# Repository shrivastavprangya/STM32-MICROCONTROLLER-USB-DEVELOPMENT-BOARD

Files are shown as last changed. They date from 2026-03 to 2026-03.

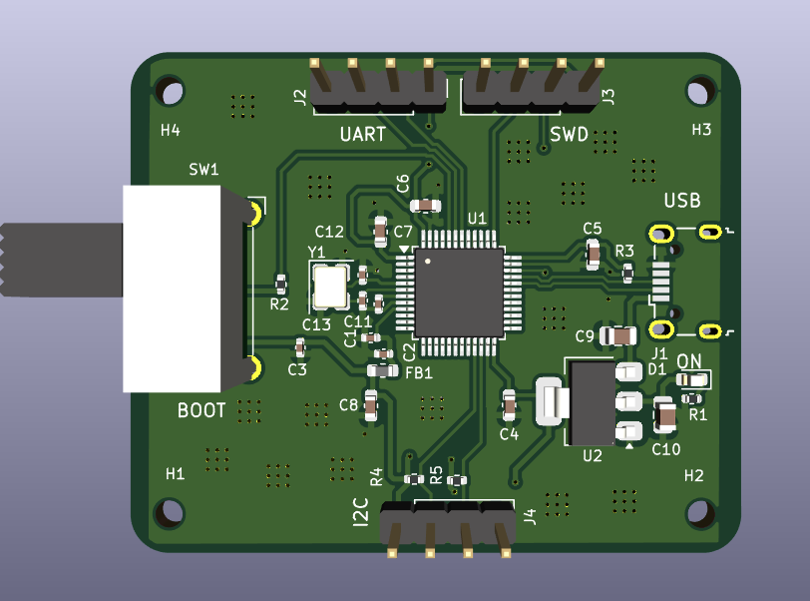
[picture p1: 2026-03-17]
STM32 TOP LAYER 3D VIEW.png

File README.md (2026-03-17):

# STM32 Microcontroller USB Development Board

This project is a custom STM32 microcontroller based USB development board designed using KiCad.  
The board includes LDO based 3.3V power regulation, USB interface for communication and power, 
external crystal oscillator for stable clock operation and GPIO expansion headers.

The PCB is designed as a 2-layer board with a dedicated ground plane for improved signal integrity 
and stable power distribution.

---

## Features

- STM32 microcontroller based development board
- USB interface for programming and communication
- 3.3V LDO voltage regulator
- External crystal oscillator for accurate clock
- Decoupling capacitors for power stability
- GPIO expansion headers
- 2-layer PCB with ground plane

---

## Design Workflow

Schematic Design  
↓  
Component Selection  
↓  
PCB Layout and Routing  
↓  
Design Rule Check (DRC)  
↓  
Gerber File Generation  
↓  
PCB Manufacturing

---

## PCB Preview

### Schematic
STM 32 PCB SCH

### PCB Layout
STM32 PCB LAYOUT

### 3D View (Top)
STM32 TOP LAYER 3D VIEW

### 3D View (Bottom)
STM32 BOTTOM LAYER 3D VIEW

---

## Project Files

- **Schematic** – KiCad schematic design files  
- **PCB Layout** – Complete PCB layout and routing files  
- **Gerber Files** – Manufacturing files used for PCB fabrication 

---

## Tools Used

- KiCad

---
## Project Structure

STM32-MICROCONTROLLER-USB-DEVELOPMENT-BOARD

│
├── Schematic
│   └── stm32_usb_board.kicad_sch
│
├── PCB
│   └── stm32_usb_board.kicad_pcb
│
├── Gerber
│   └── gerber_files.zip
│
├── Images
│   ├── pcb_top.png
│   ├── pcb_bottom.png
│   └── pcb_3d.png
│
└── README.md

## Author

**Pragya Shrivastav**  
Electronics & Communication Engineer  
PCB Design | Embedded Hardware

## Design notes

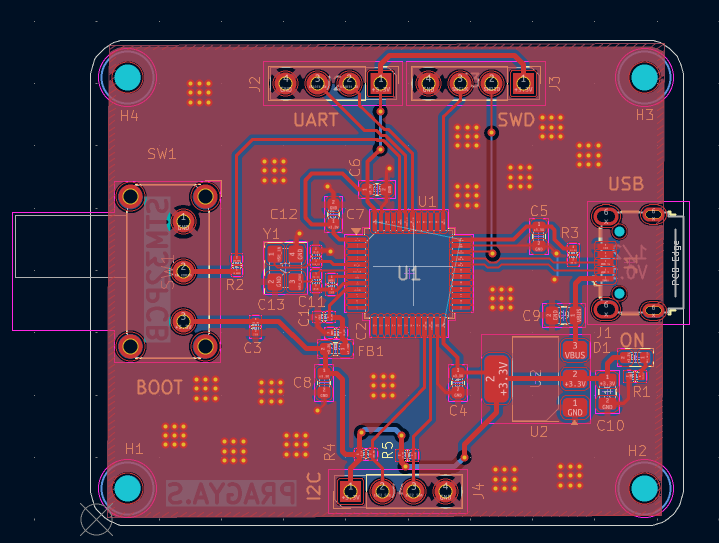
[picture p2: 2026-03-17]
STM32 PCB LAYOUT.png

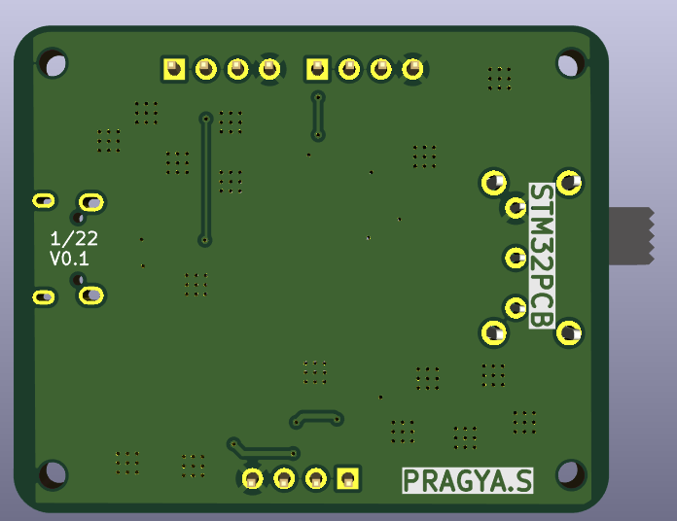
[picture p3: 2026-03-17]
STM32 BOTTOM LAYER 3D VIEW.png

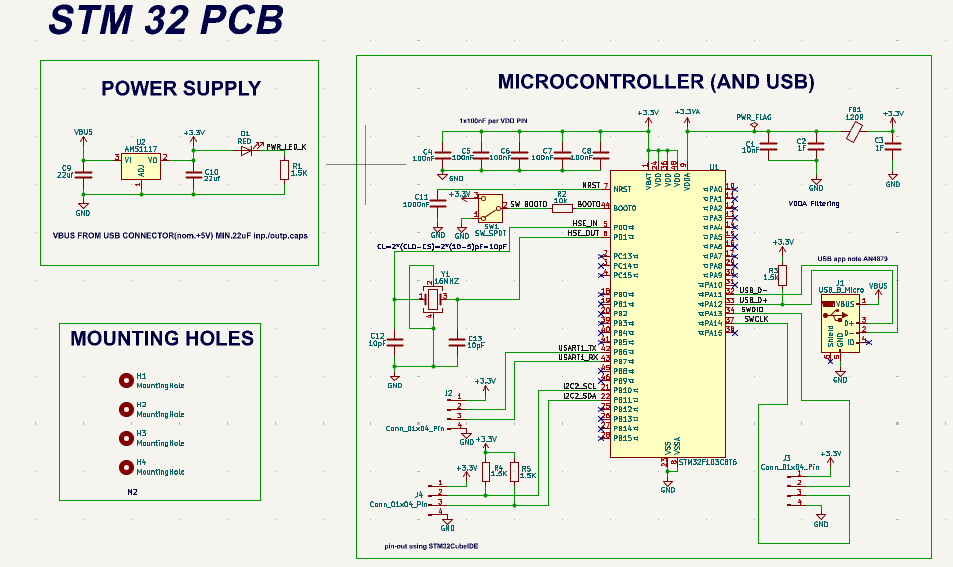
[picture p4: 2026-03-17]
STM 32 PCB SCH.png

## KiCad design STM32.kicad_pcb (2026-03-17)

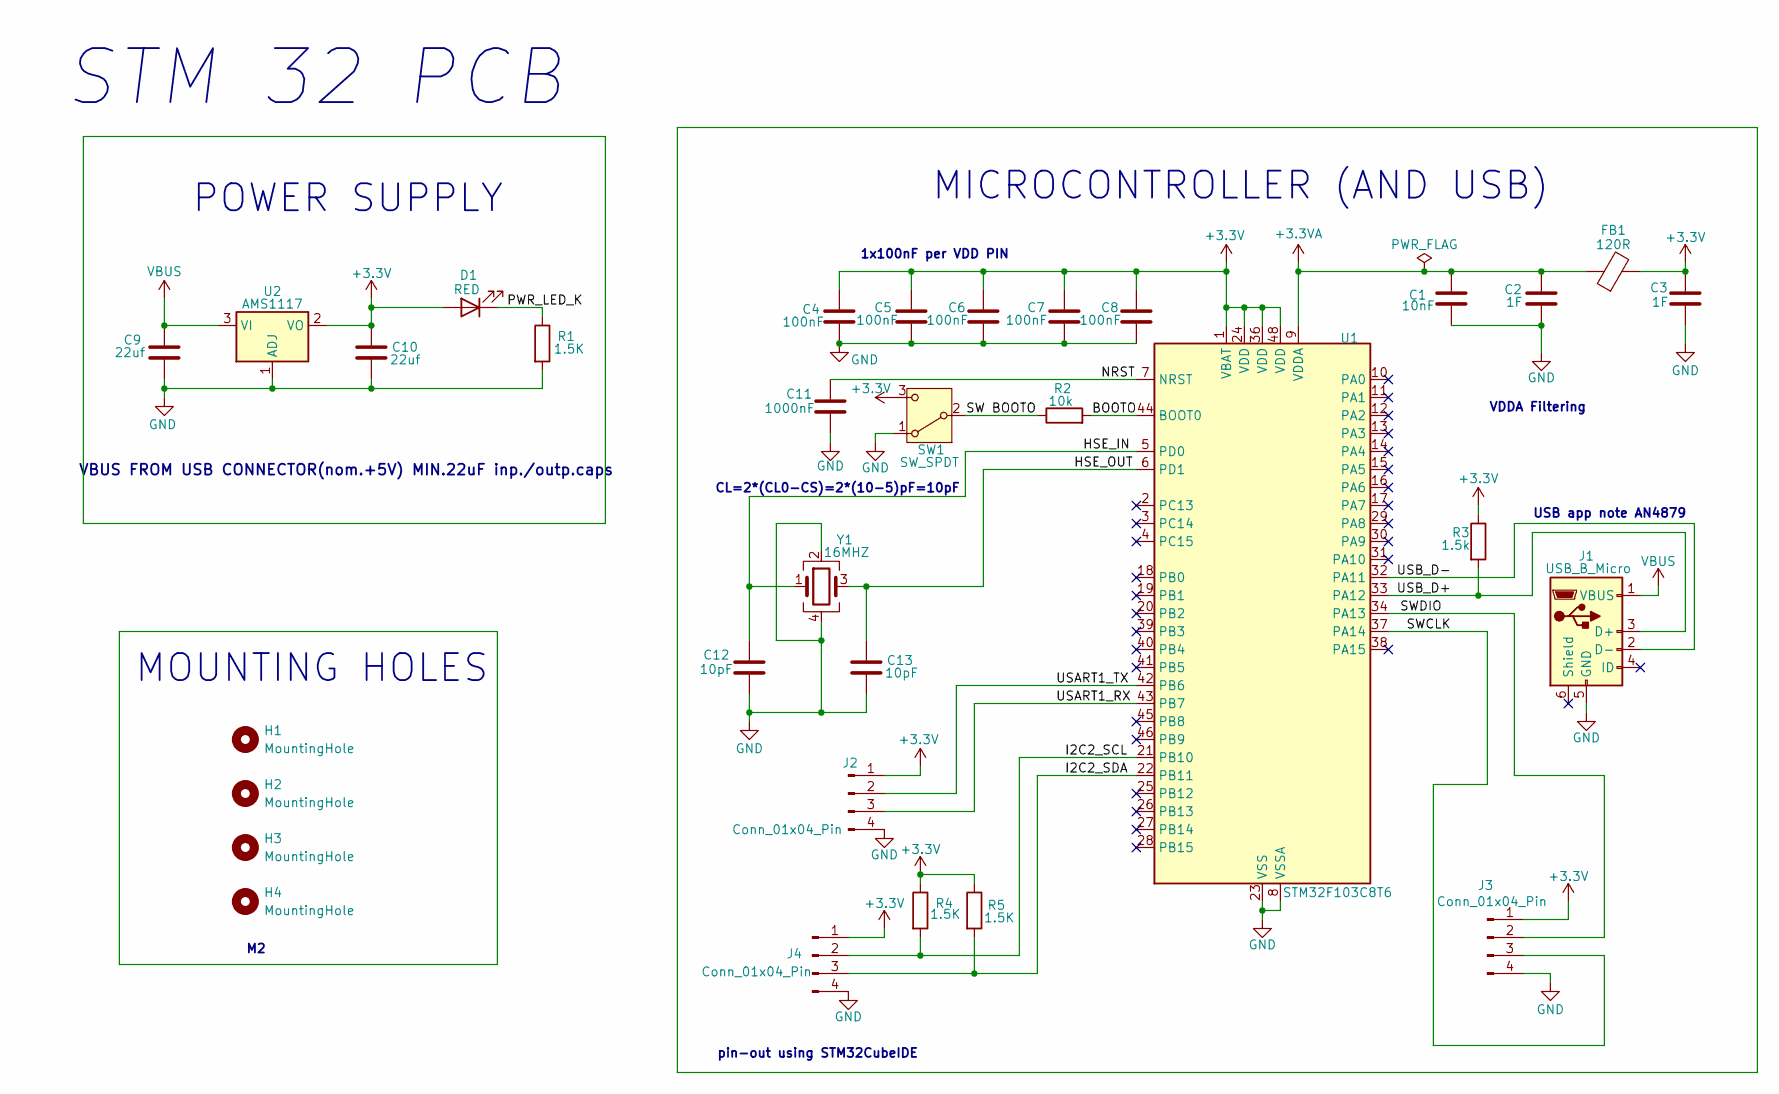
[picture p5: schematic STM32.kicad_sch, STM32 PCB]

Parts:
C1: 10nF; C_0402_1005Metric
C2, C3: 1F; C_0402_1005Metric
C4, C5, C6, C7, C8: 100nF; C_0603_1608Metric
C9, C10: 22uf; C_0805_2012Metric
C11: 1000nF; C_0402_1005Metric
C12, C13: 10pF; C_0402_1005Metric
D1: RED; LED_0603_1608Metric
FB1: 120R; L_0603_1608Metric
H1, H2, H3, H4: MountingHole; MountingHole_2.1mm
J1: USB_B_Micro; USB_Micro-B_Wuerth_629105150521
J2, J3, J4: Conn_01x04_Pin; PinHeader_1x04_P2.54mm_Vertical
R1, R4, R5: 1.5K; R_0402_1005Metric
R2: 10k; R_0402_1005Metric
R3: 1.5k; R_0402_1005Metric
SW1: SW_SPDT; SW_E-Switch_EG1224_SPDT_Angled
U1: STM32F103C8T6; LQFP-48_7x7mm_P0.5mm
U2: AMS1117; SOT-223-3_TabPin2
Y1: 16MHZ; Crystal_SMD_3225-4Pin_3.2x2.5mm

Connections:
+3.3V: C3.1, C4.1, C5.1, C6.1, C7.1, C8.1, C10.1, D1.2 (A), FB1.2, J2.1, J3.1, J4.1, R3.1, R4.1, R5.1, SW1.3 (C), U1.1 (VBAT), U1.24 (VDD), U1.36 (VDD), U1.48 (VDD), U2.2 (VO)
+3.3VA: C1.1, C2.1, FB1.1, U1.9 (VDDA)
/BOOTO: R2.2, U1.44 (BOOT0)
/HSE_IN: C12.1, U1.5 (PD0), Y1.1
/HSE_OUT: C13.1, U1.6 (PD1), Y1.3
/I2C2_SCL: J4.2, R4.2, U1.21 (PB10)
/I2C2_SDA: J4.3, R5.2, U1.22 (PB11)
/NRST: C11.1, U1.7 (NRST)
/PWR_LED_K: D1.1 (K), R1.1
/SW BOOTO: R2.1, SW1.2 (B)
/SWCLK: J3.3, U1.37 (PA14)
/SWDIO: J3.2, U1.34 (PA13)
/USART1_RX: J2.3, U1.43 (PB7)
/USART1_TX: J2.2, U1.42 (PB6)
/USB_D+: J1.3 (D+), R3.2, U1.33 (PA12)
/USB_D-: J1.2 (D-), U1.32 (PA11)
GND: C1.2, C2.2, C3.2, C4.2, C5.2, C6.2, C7.2, C8.2, C9.2, C10.2, C11.2, C12.2, C13.2, J1.5 (GND), J2.4, J3.4, J4.4, R1.2, SW1.1 (A), U1.8 (VSSA), U1.23 (VSS), U1.35 (VSS), U1.47 (VSS), U2.1 (ADJ), Y1.2, Y1.4
VBUS: C9.1, J1.1 (VBUS), U2.3 (VI)

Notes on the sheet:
POWER SUPPLY
1x100nF per VDD PIN
USB app note AN4879
VBUS FROM USB CONNECTOR(nom.+5V) MIN.22uF inp./outp.caps
MOUNTING HOLES
CL=2*(CL0-CS)=2*(10-5)pF=10pF
pin-out using STM32CubeIDE
VDDA Filtering
MICROCONTROLLER (AND USB)
STM 32 PCB

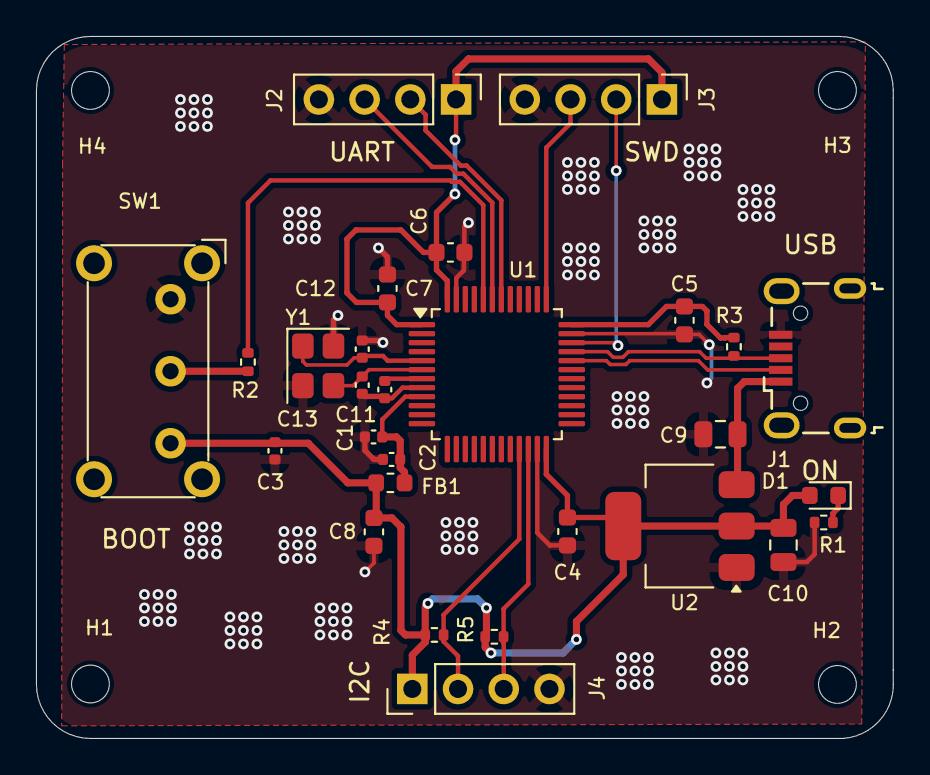
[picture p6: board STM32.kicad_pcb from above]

Board: 2 copper layers, 47.6 x 39.0 mm, 32 parts (0 on the bottom side), 18 nets.
